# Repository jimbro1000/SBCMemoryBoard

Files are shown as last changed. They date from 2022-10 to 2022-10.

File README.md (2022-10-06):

# HD6309SBC Mapped Memory Board

This is a design for memory expansion of the HD6309 single board 
computer I designed (See https://github.com/jimbro1000/HD6309sbc)

The board provides the full 64k RAM model (rather than the 50:50
RAM/ROM model) plus paged memory mapped in at $8000. The current
design includes 1MB of paged memory but can handle up to 4MB.

It is up to the programmer to make sure code is safe to handle
page swaps and avoid broken stacks, etc.

## Hardware registers

The switching of memory pages is handled by writing to address 
$FF25. The value is effectively address lines 14 to 21 of the 
extended memory.

Whichever page is selected is mapped to a base address of $8000 
for the CPU.

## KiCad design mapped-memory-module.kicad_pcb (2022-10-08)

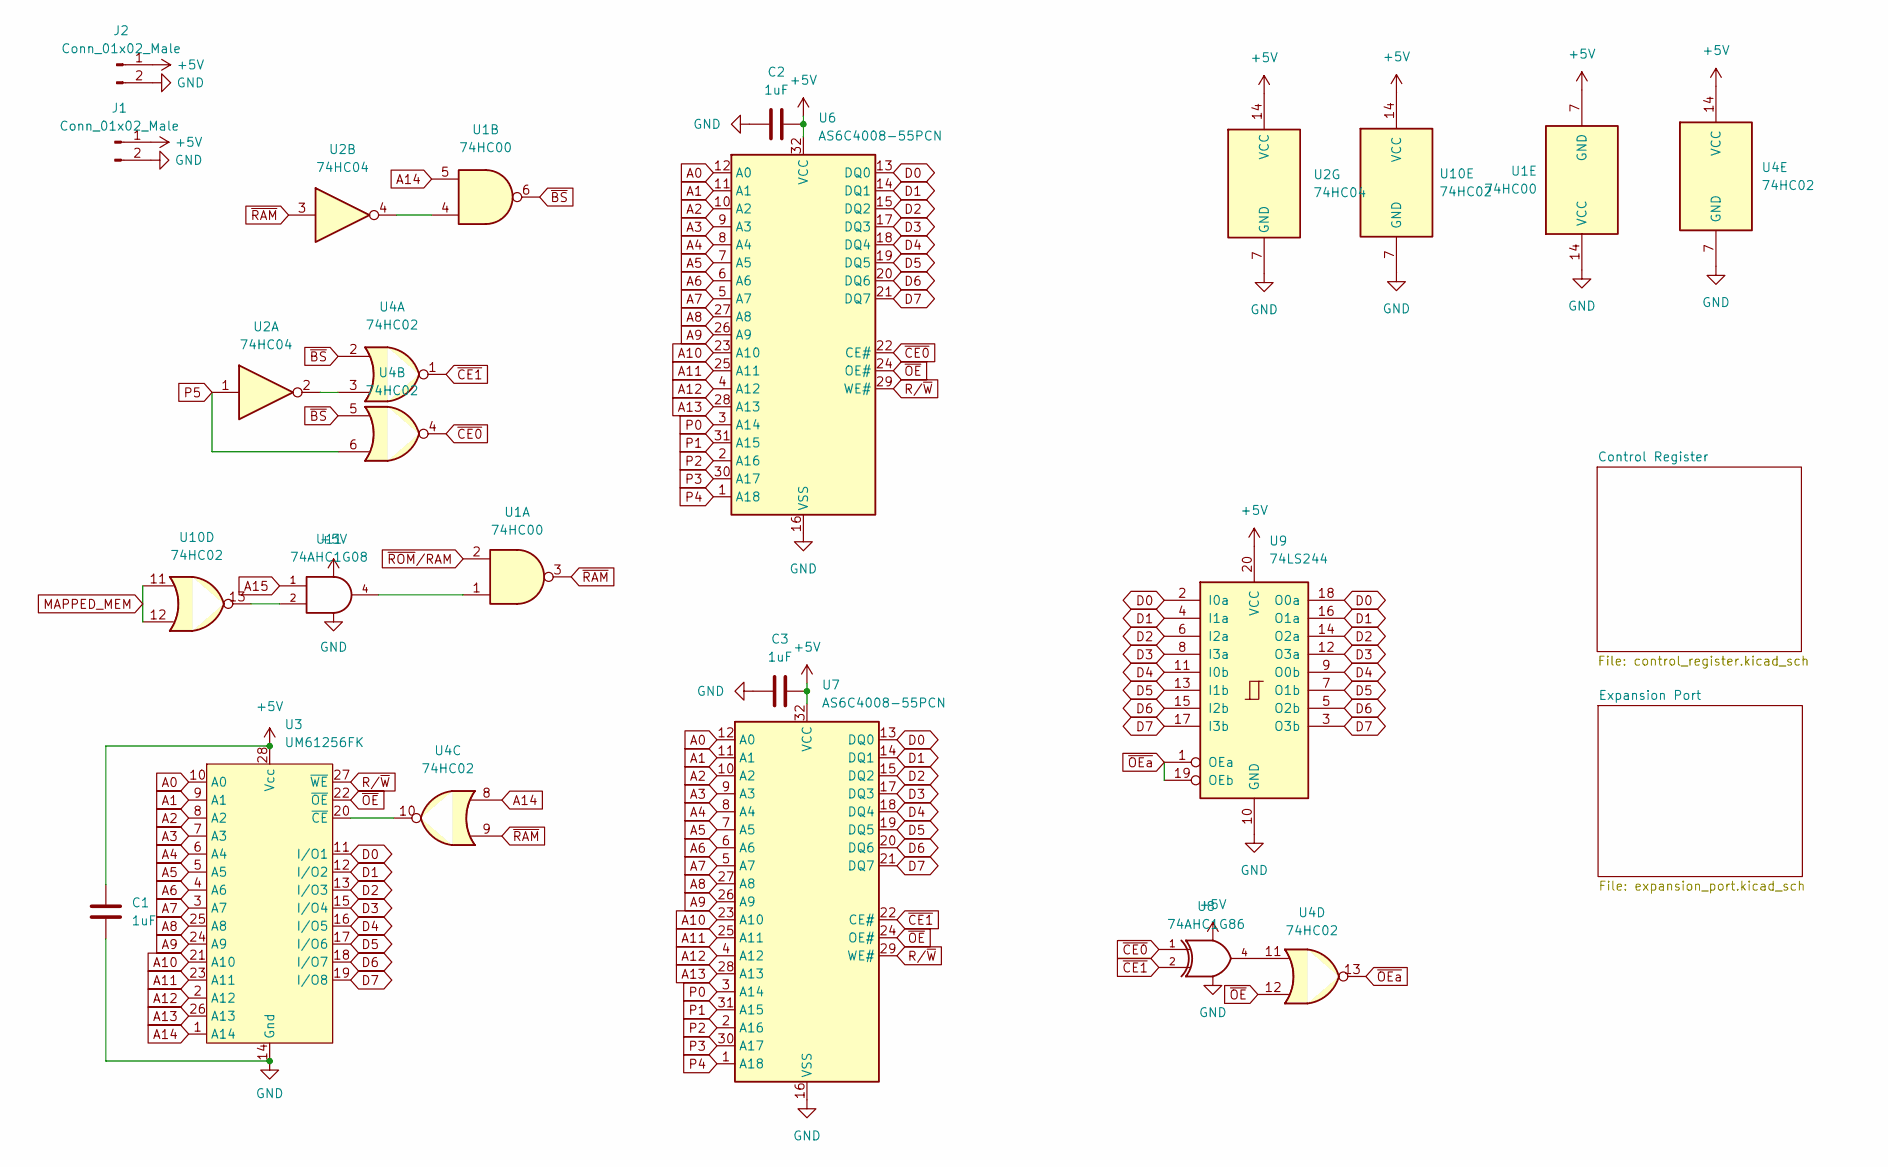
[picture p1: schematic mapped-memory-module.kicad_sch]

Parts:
C1, C2, C3: 1uF; C_0805_2012Metric
J1, J2: Conn_01x02_Male; PinHeader_1x02_P2.54mm_Vertical
U1: 74HC00; SO-14_3.9x8.65mm_P1.27mm
U2: 74HC04; SO-14_3.9x8.65mm_P1.27mm
U3: UM61256FK; DIP-28_W7.62mm
U4, U10: 74HC02; SO-14_3.9x8.65mm_P1.27mm
U6, U7: AS6C4008-55PCN; SSOP-32_11.305x20.495mm_P1.27mm
U8: 74AHC1G86; TSOP-5_1.65x3.05mm_P0.95mm
U9: 74LS244; SO-20_5.3x12.6mm_P1.27mm
U11: 74AHC1G08; TSOP-5_1.65x3.05mm_P0.95mm

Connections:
+5V: C1.1, C2.1, C3.1, J1.1, J2.1, U1.7 (GND), U2.14 (VCC), U3.28 (Vcc), U4.14 (VCC), U6.32 (VCC), U7.32 (VCC), U8.5 (VCC), U9.20 (VCC), U10.14 (VCC), U11.5 (VCC); also elsewhere on the board
A0: U3.10 (A0), U6.12 (A0), U7.12 (A0); also elsewhere on the board
A1: U3.9 (A1), U6.11 (A1), U7.11 (A1); also elsewhere on the board
A2: U3.8 (A2), U6.10 (A2), U7.10 (A2); also elsewhere on the board
A3: U3.7 (A3), U6.9 (A3), U7.9 (A3); also elsewhere on the board
A4: U3.6 (A4), U6.8 (A4), U7.8 (A4); also elsewhere on the board
A5: U3.5 (A5), U6.7 (A5), U7.7 (A5); also elsewhere on the board
A6: U3.4 (A6), U6.6 (A6), U7.6 (A6); also elsewhere on the board
A7: U3.3 (A7), U6.5 (A7), U7.5 (A7); also elsewhere on the board
A8: U3.25 (A8), U6.27 (A8), U7.27 (A8); also elsewhere on the board
A9: U3.24 (A9), U6.26 (A9), U7.26 (A9); also elsewhere on the board
A10: U3.21 (A10), U6.23 (A10), U7.23 (A10); also elsewhere on the board
A11: U3.23 (A11), U6.25 (A11), U7.25 (A11); also elsewhere on the board
A12: U3.2 (A12), U6.4 (A12), U7.4 (A12); also elsewhere on the board
A13: U3.26 (A13), U6.28 (A13), U7.28 (A13); also elsewhere on the board
A14: U1.5, U3.1 (A14), U4.8; also elsewhere on the board
A15: U11.1; also elsewhere on the board
D0: U3.11 (I/O1), U6.13 (DQ0), U7.13 (DQ0), U9.2 (I0a), U9.18 (O0a); also elsewhere on the board
D1: U3.12 (I/O2), U6.14 (DQ1), U7.14 (DQ1), U9.4 (I1a), U9.16 (O1a); also elsewhere on the board
D2: U3.13 (I/O3), U6.15 (DQ2), U7.15 (DQ2), U9.6 (I2a), U9.14 (O2a); also elsewhere on the board
D3: U3.15 (I/O4), U6.17 (DQ3), U7.17 (DQ3), U9.8 (I3a), U9.12 (O3a); also elsewhere on the board
D4: U3.16 (I/O5), U6.18 (DQ4), U7.18 (DQ4), U9.9 (O0b), U9.11 (I0b); also elsewhere on the board
D5: U3.17 (I/O6), U6.19 (DQ5), U7.19 (DQ5), U9.7 (O1b), U9.13 (I1b); also elsewhere on the board
D6: U3.18 (I/O7), U6.20 (DQ6), U7.20 (DQ6), U9.5 (O2b), U9.15 (I2b); also elsewhere on the board
D7: U3.19 (I/O8), U6.21 (DQ7), U7.21 (DQ7), U9.3 (O3b), U9.17 (I3b); also elsewhere on the board
GND: C1.2, C2.2, C3.2, J1.2, J2.2, U1.14 (VCC), U2.7 (GND), U3.14 (Gnd), U4.7 (GND), U6.16 (VSS), U7.16 (VSS), U8.3 (GND), U9.10 (GND), U10.7 (GND), U11.3 (GND); also elsewhere on the board
MAPPED_MEM: U10.11, U10.12; also elsewhere on the board
unnamed: U1.1, U11.4
unnamed: U1.4, U2.4
unnamed: U2.2, U4.3
unnamed: U3.20 (~CE), U4.10
unnamed: U4.11, U8.4
unnamed: U10.13, U11.2
P0: U6.3 (A14), U7.3 (A14); also elsewhere on the board
P1: U6.31 (A15), U7.31 (A15); also elsewhere on the board
P2: U6.2 (A16), U7.2 (A16); also elsewhere on the board
P3: U6.30 (A17), U7.30 (A17); also elsewhere on the board
P4: U6.1 (A18), U7.1 (A18); also elsewhere on the board
P5: U2.1, U4.6; also elsewhere on the board
R/~W: U3.27 (~WE), U6.29 (WE#), U7.29 (WE#); also elsewhere on the board
~BS: U1.6, U4.2, U4.5
~CE0: U4.4, U6.22 (CE#), U8.1
~CE1: U4.1, U7.22 (CE#), U8.2
~OEa: U4.13, U9.1 (OEa), U9.19 (OEb)
~OE: U3.22 (~OE), U4.12, U6.24 (OE#), U7.24 (OE#)
~RAM: U1.3, U2.3, U4.9
~ROM/RAM: U1.2

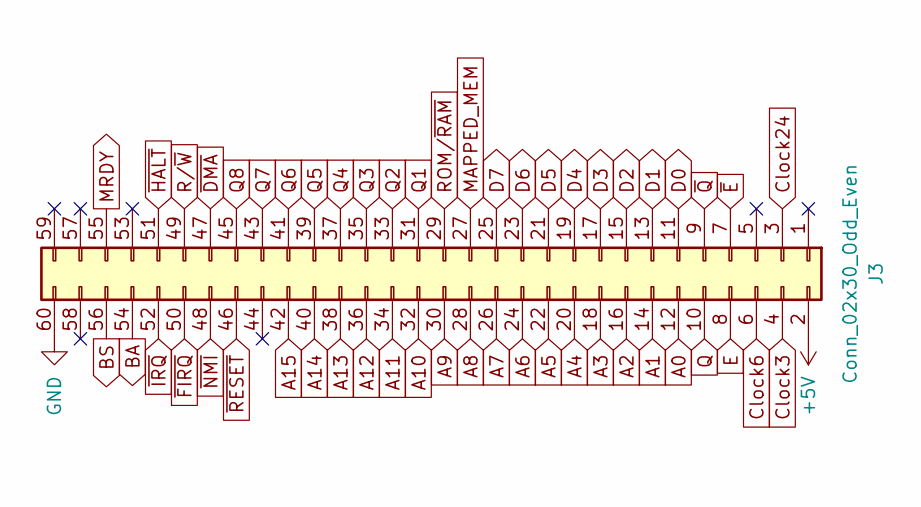
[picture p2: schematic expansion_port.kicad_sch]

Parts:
J3: Conn_02x30_Odd_Even; PinHeader_2x30_P2.54mm_Vertical

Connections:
+5V: J3.2; also elsewhere on the board
A0: J3.12; also elsewhere on the board
A1: J3.14; also elsewhere on the board
A2: J3.16; also elsewhere on the board
A3: J3.18; also elsewhere on the board
A4: J3.20; also elsewhere on the board
A5: J3.22; also elsewhere on the board
A6: J3.24; also elsewhere on the board
A7: J3.26; also elsewhere on the board
A8: J3.28; also elsewhere on the board
A9: J3.30; also elsewhere on the board
A10: J3.32; also elsewhere on the board
A11: J3.34; also elsewhere on the board
A12: J3.36; also elsewhere on the board
A13: J3.38; also elsewhere on the board
A14: J3.40; also elsewhere on the board
A15: J3.42; also elsewhere on the board
BA: J3.54
BS: J3.56
Clock3: J3.4
Clock6: J3.6
Clock24: J3.3
D0: J3.11; also elsewhere on the board
D1: J3.13; also elsewhere on the board
D2: J3.15; also elsewhere on the board
D3: J3.17; also elsewhere on the board
D4: J3.19; also elsewhere on the board
D5: J3.21; also elsewhere on the board
D6: J3.23; also elsewhere on the board
D7: J3.25; also elsewhere on the board
E: J3.8
GND: J3.60; also elsewhere on the board
MAPPED_MEM: J3.27; also elsewhere on the board
MRDY: J3.55
Q: J3.10
Q1: J3.31
Q2: J3.33
Q3: J3.35
Q4: J3.37
Q5: J3.39
Q6: J3.41
Q7: J3.43
Q8: J3.45
ROM/~RAM: J3.29
R/~W: J3.49; also elsewhere on the board
~DMA: J3.47
~E: J3.7
~FIRQ: J3.50
~HALT: J3.51
~IRQ: J3.52
~NMI: J3.48
~Q: J3.9
~RESET: J3.46

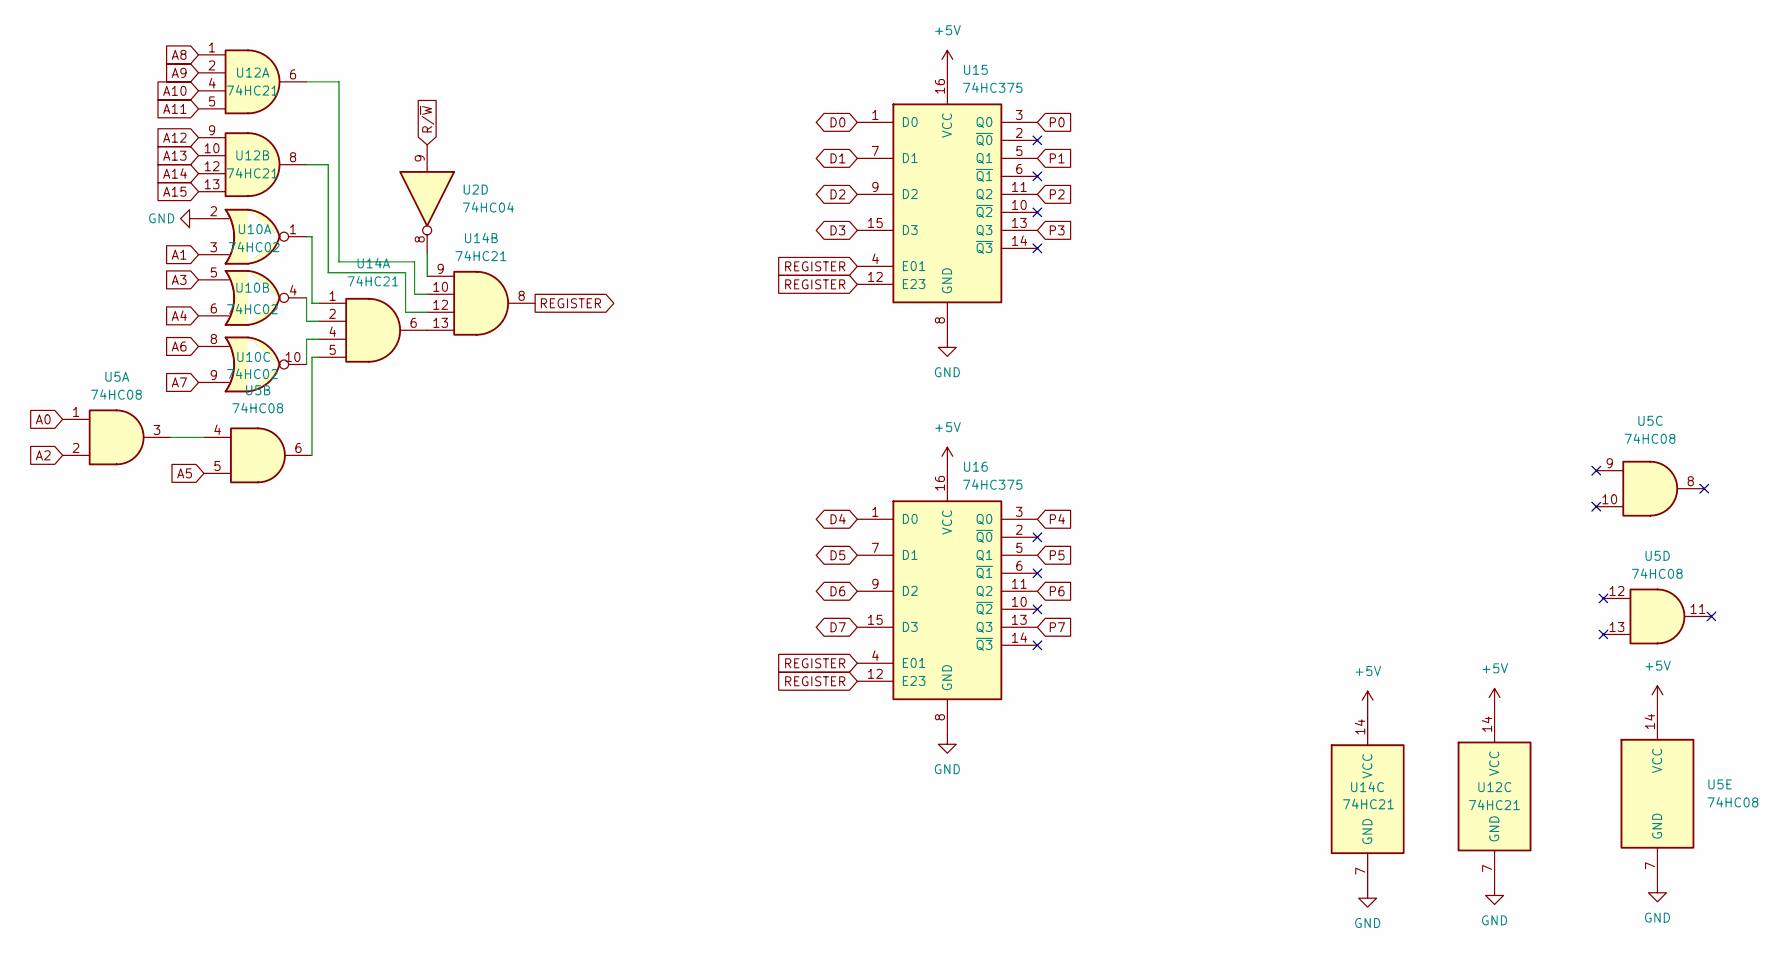
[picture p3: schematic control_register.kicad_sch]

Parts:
U2: 74HC04; SO-14_3.9x8.65mm_P1.27mm
U5: 74HC08; SO-14_3.9x8.65mm_P1.27mm
U10: 74HC02; SO-14_3.9x8.65mm_P1.27mm
U12, U14: 74HC21; SO-14_3.9x8.65mm_P1.27mm
U15, U16: 74HC375; SO-16_3.9x9.9mm_P1.27mm

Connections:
+5V: U5.14 (VCC), U12.14 (VCC), U14.14 (VCC), U15.16 (VCC), U16.16 (VCC); also elsewhere on the board
A0: U5.1; also elsewhere on the board
A1: U10.3; also elsewhere on the board
A2: U5.2; also elsewhere on the board
A3: U10.5; also elsewhere on the board
A4: U10.6; also elsewhere on the board
A5: U5.5; also elsewhere on the board
A6: U10.8; also elsewhere on the board
A7: U10.9; also elsewhere on the board
A8: U12.1; also elsewhere on the board
A9: U12.2; also elsewhere on the board
A10: U12.4; also elsewhere on the board
A11: U12.5; also elsewhere on the board
A12: U12.9; also elsewhere on the board
A13: U12.10; also elsewhere on the board
A14: U12.12; also elsewhere on the board
A15: U12.13; also elsewhere on the board
D0: U15.1 (D0); also elsewhere on the board
D1: U15.7 (D1); also elsewhere on the board
D2: U15.9 (D2); also elsewhere on the board
D3: U15.15 (D3); also elsewhere on the board
D4: U16.1 (D0); also elsewhere on the board
D5: U16.7 (D1); also elsewhere on the board
D6: U16.9 (D2); also elsewhere on the board
D7: U16.15 (D3); also elsewhere on the board
GND: U5.7 (GND), U10.2, U12.7 (GND), U14.7 (GND), U15.8 (GND), U16.8 (GND); also elsewhere on the board
unnamed: U5.3, U5.4
unnamed: U10.1, U14.1
unnamed: U10.4, U14.2
unnamed: U10.10, U14.4
unnamed: U12.6, U14.10
unnamed: U12.8, U14.12
unnamed: U5.6, U14.5
unnamed: U2.8, U14.9
unnamed: U14.6, U14.13
P0: U15.3 (Q0); also elsewhere on the board
P1: U15.5 (Q1); also elsewhere on the board
P2: U15.11 (Q2); also elsewhere on the board
P3: U15.13 (Q3); also elsewhere on the board
P4: U16.3 (Q0); also elsewhere on the board
P5: U16.5 (Q1); also elsewhere on the board
P6: U16.11 (Q2)
P7: U16.13 (Q3)
REGISTER: U14.8, U15.4 (E01), U15.12 (E23), U16.4 (E01), U16.12 (E23)
R/~W: U2.9; also elsewhere on the board

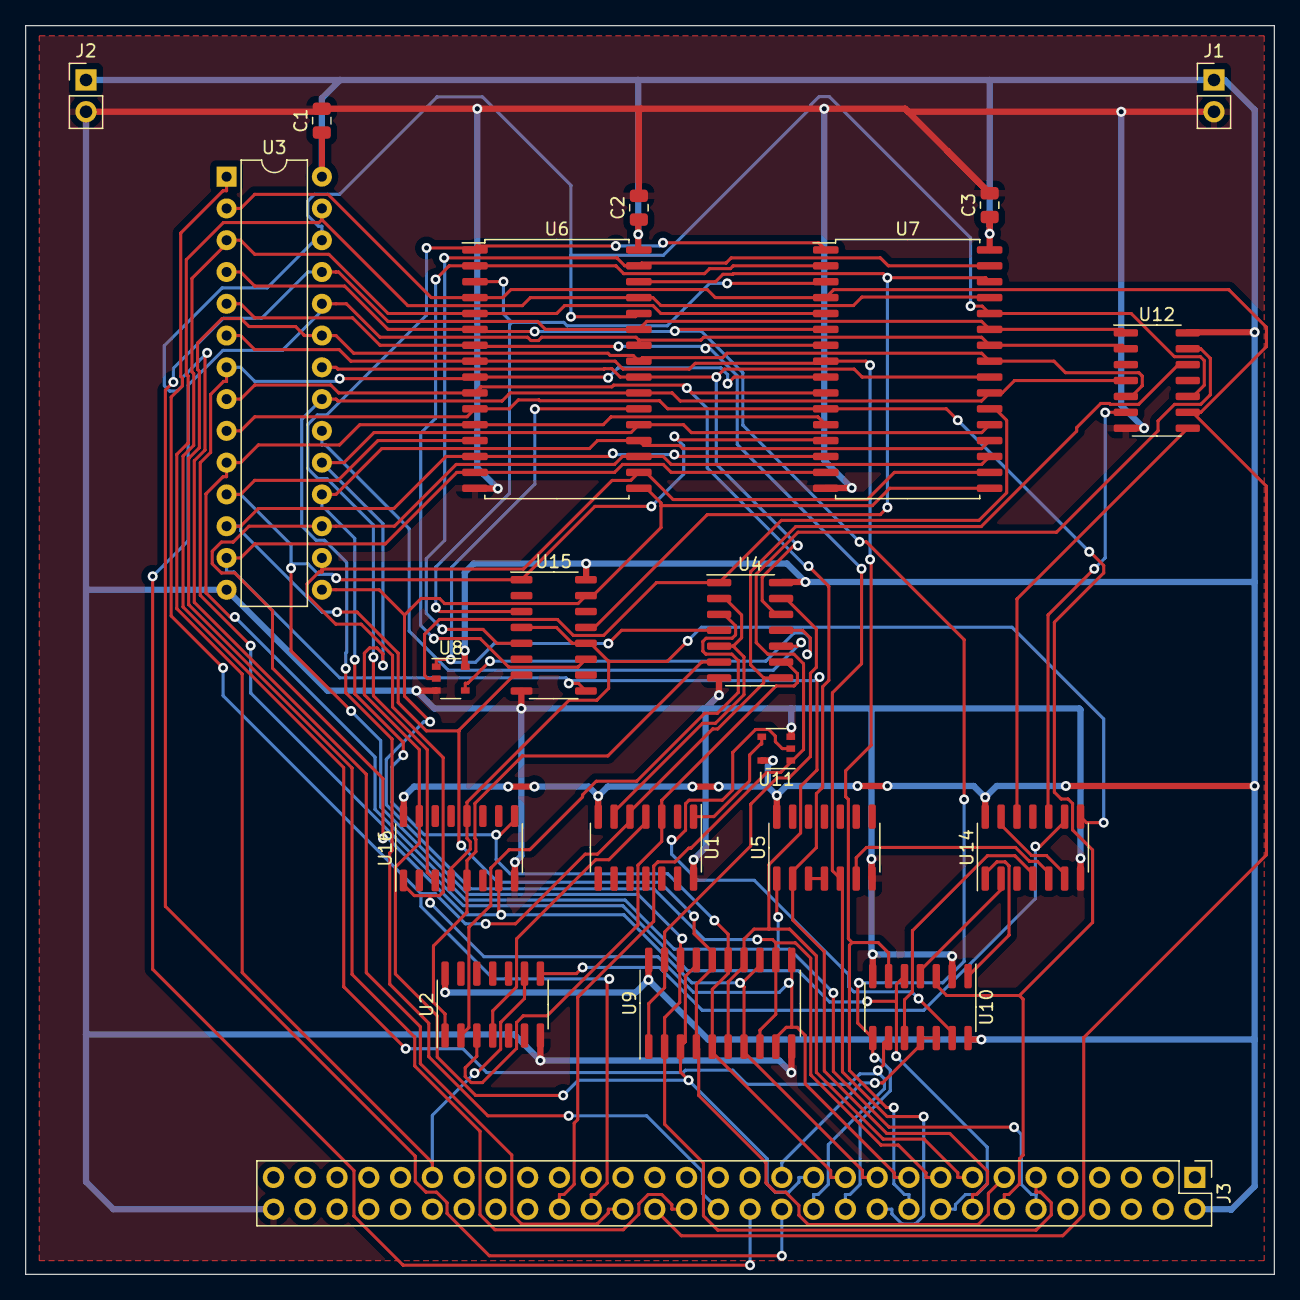
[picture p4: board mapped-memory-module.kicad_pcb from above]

Board: 2 copper layers, 99.8 x 99.8 mm, 21 parts (0 on the bottom side), 56 nets.

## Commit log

2022-10-06 fit to sbc design standard
    [control_register.kicad_sch, expansion_port.kicad_sch, mapped-memory-module.dsn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]
2022-10-06 add bom
2022-10-08 add mapped memory lane
    [control_register.kicad_sch, expansion_port.kicad_sch, mapped-memory-module.dsn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]
